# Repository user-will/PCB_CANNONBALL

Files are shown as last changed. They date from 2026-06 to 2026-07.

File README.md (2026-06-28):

# REIL INDUSTRIAL - CANNONBALL

A feature-packed ESP32-C3 development board built around the **ESP32-C3-WROOM-02-N4**, designed to be the last board you need for any project — smart home device, RC car, wearable, or anything else you can dream up.

The big pitch: pull a single-cell LiPo or Li-ion from an old vape, plug it into the JST PH connector, and go. The board handles charging, protection, and fuel gauging — no external circuitry needed.

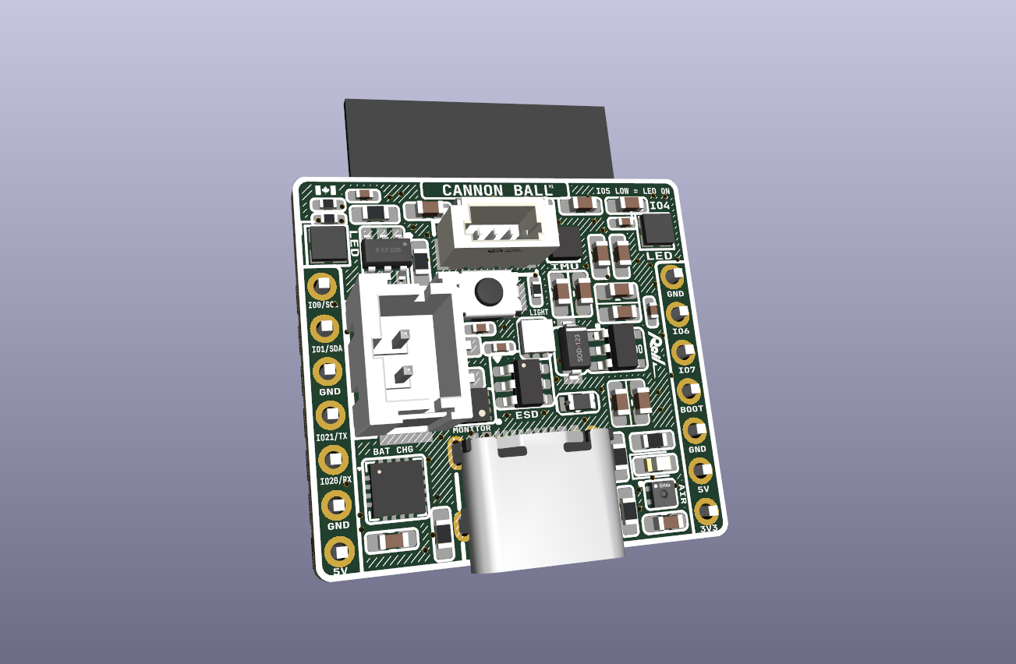
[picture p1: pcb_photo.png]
PCB Photo


---

## Features

- **MCU** — ESP32-C3-WROOM-02-N4 (RISC-V, 2.4 GHz Wi-Fi + BLE, 4 MB flash)
- **USB protection** — USBLC6-4SC6 TVS diode array on the USB lines
- **Battery charging** — BQ24075RGT linear charger (100 mA default, 500 mA selectable via GPIO)
- **Battery protection** — DW01A + FS8205A dual MOSFET pack (over-charge, over-discharge, short circuit)
- **Battery monitoring** — MAX17048 fuel gauge over I2C with low-battery alert
- **3.3 V regulation** — AP2112K-3.3 LDO
- **Addressable LEDs** — SK6812-EC20 RGB LEDs switched via DMG2301L MOSFET
- **IMU** — LSM6DS3 (6-axis accelerometer + gyroscope, I2C)
- **Temp & humidity** — SHT40 (I2C)
- **Light sensor** — VEML6030 ambient light sensor (I2C)
- **I2C expansion** — JST SH 1.0 mm 4-pin connector (3.3 V, GND, SDA, SCL)
- **Battery connector** — JST PH 2.0 mm 2-pin

---

## Power

| Rail | Source | Voltage | Notes |
|---|---|---|---|
| USB-C | External | 5 V nominal, **6 V max** | Limited by AP2112K-3.3 LDO max input. Do not exceed 6 V on the 5 V pins or USB input. |
| 5V pin (J5/J6) | External or VBUS | 5 V nominal, **6 V max** | Same rail as USB VBUS — feeds the LDO and charger directly. |
| 3V3 pin (J4/J6) | AP2112K-3.3 LDO | **3.3 V exactly** | If powering the board externally via the 3V3 pin (bypassing the LDO), supply a regulated 3.3 V. The ESP32 and all peripherals run at 3.3 V with a ±0.3 V tolerance — do not exceed 3.6 V or drop below 3.0 V. |

---

## Pin Reference

| GPIO | Function | Notes |
|---|---|---|
| 3 | MAX17048 alert | Active-low interrupt when battery is low |
| 4 | SK6812 data | Addressable LED data line |
| 5 | LED enable (MOSFET) | Pull **high** to enable LEDs, low to disable |
| 10 | BQ24075 EN1 (charge rate) | Pull **high** to increase charge current from 100 mA to 500 mA |

---

## Bill of Materials

| Reference | Part | Function |
|---|---|---|
| U1 | ESP32-C3-WROOM-02-N4 | Main MCU |
| U2 | BQ24075RGT | Li-ion/LiPo battery charger |
| U3 | MAX17048 | Battery fuel gauge (I2C) |
| U4 | DW01A | Battery protection IC |
| U5 | FS8205A | Dual MOSFET for battery protection |
| U6 | AP2112K-3.3 | 3.3 V LDO regulator |
| U7 | USBLC6-4SC6 | USB ESD/TVS protection |
| U8 | LSM6DS3 | 6-axis IMU (I2C) |
| U9 | SHT40 | Temperature & humidity sensor (I2C) |
| U10 | VEML6030 | Ambient light sensor (I2C) |
| Q3 | 2N7002K | N-channel MOSFET (LED power switch) |
| LED1+ | SK6812-EC20 | Addressable RGB LEDs |

---

## Opening in KiCad

1. Clone or download this repo
2. Open KiCad and select **File → Open Project**
3. Navigate to the repo folder and open `CANNONBALL.kicad_pro`

All schematic symbols and footprints are either embedded in the project files or included in the `jlcpcb.pretty/` and `jlcpcb.kicad_sym` local libraries — no additional library setup required.

---

## Battery Compatibility

Any single-cell LiPo or Li-ion (3.6–4.2 V nominal) will work. The onboard protection circuit guards against:
- Over-charge (> 4.2 V)
- Over-discharge (< 2.5 V)
- Short circuit / over-current

Cells salvaged from vapes, old phones, or RC packs all work fine. Use the JST PH 2.0 mm 2-pin connector (positive on pin 1).

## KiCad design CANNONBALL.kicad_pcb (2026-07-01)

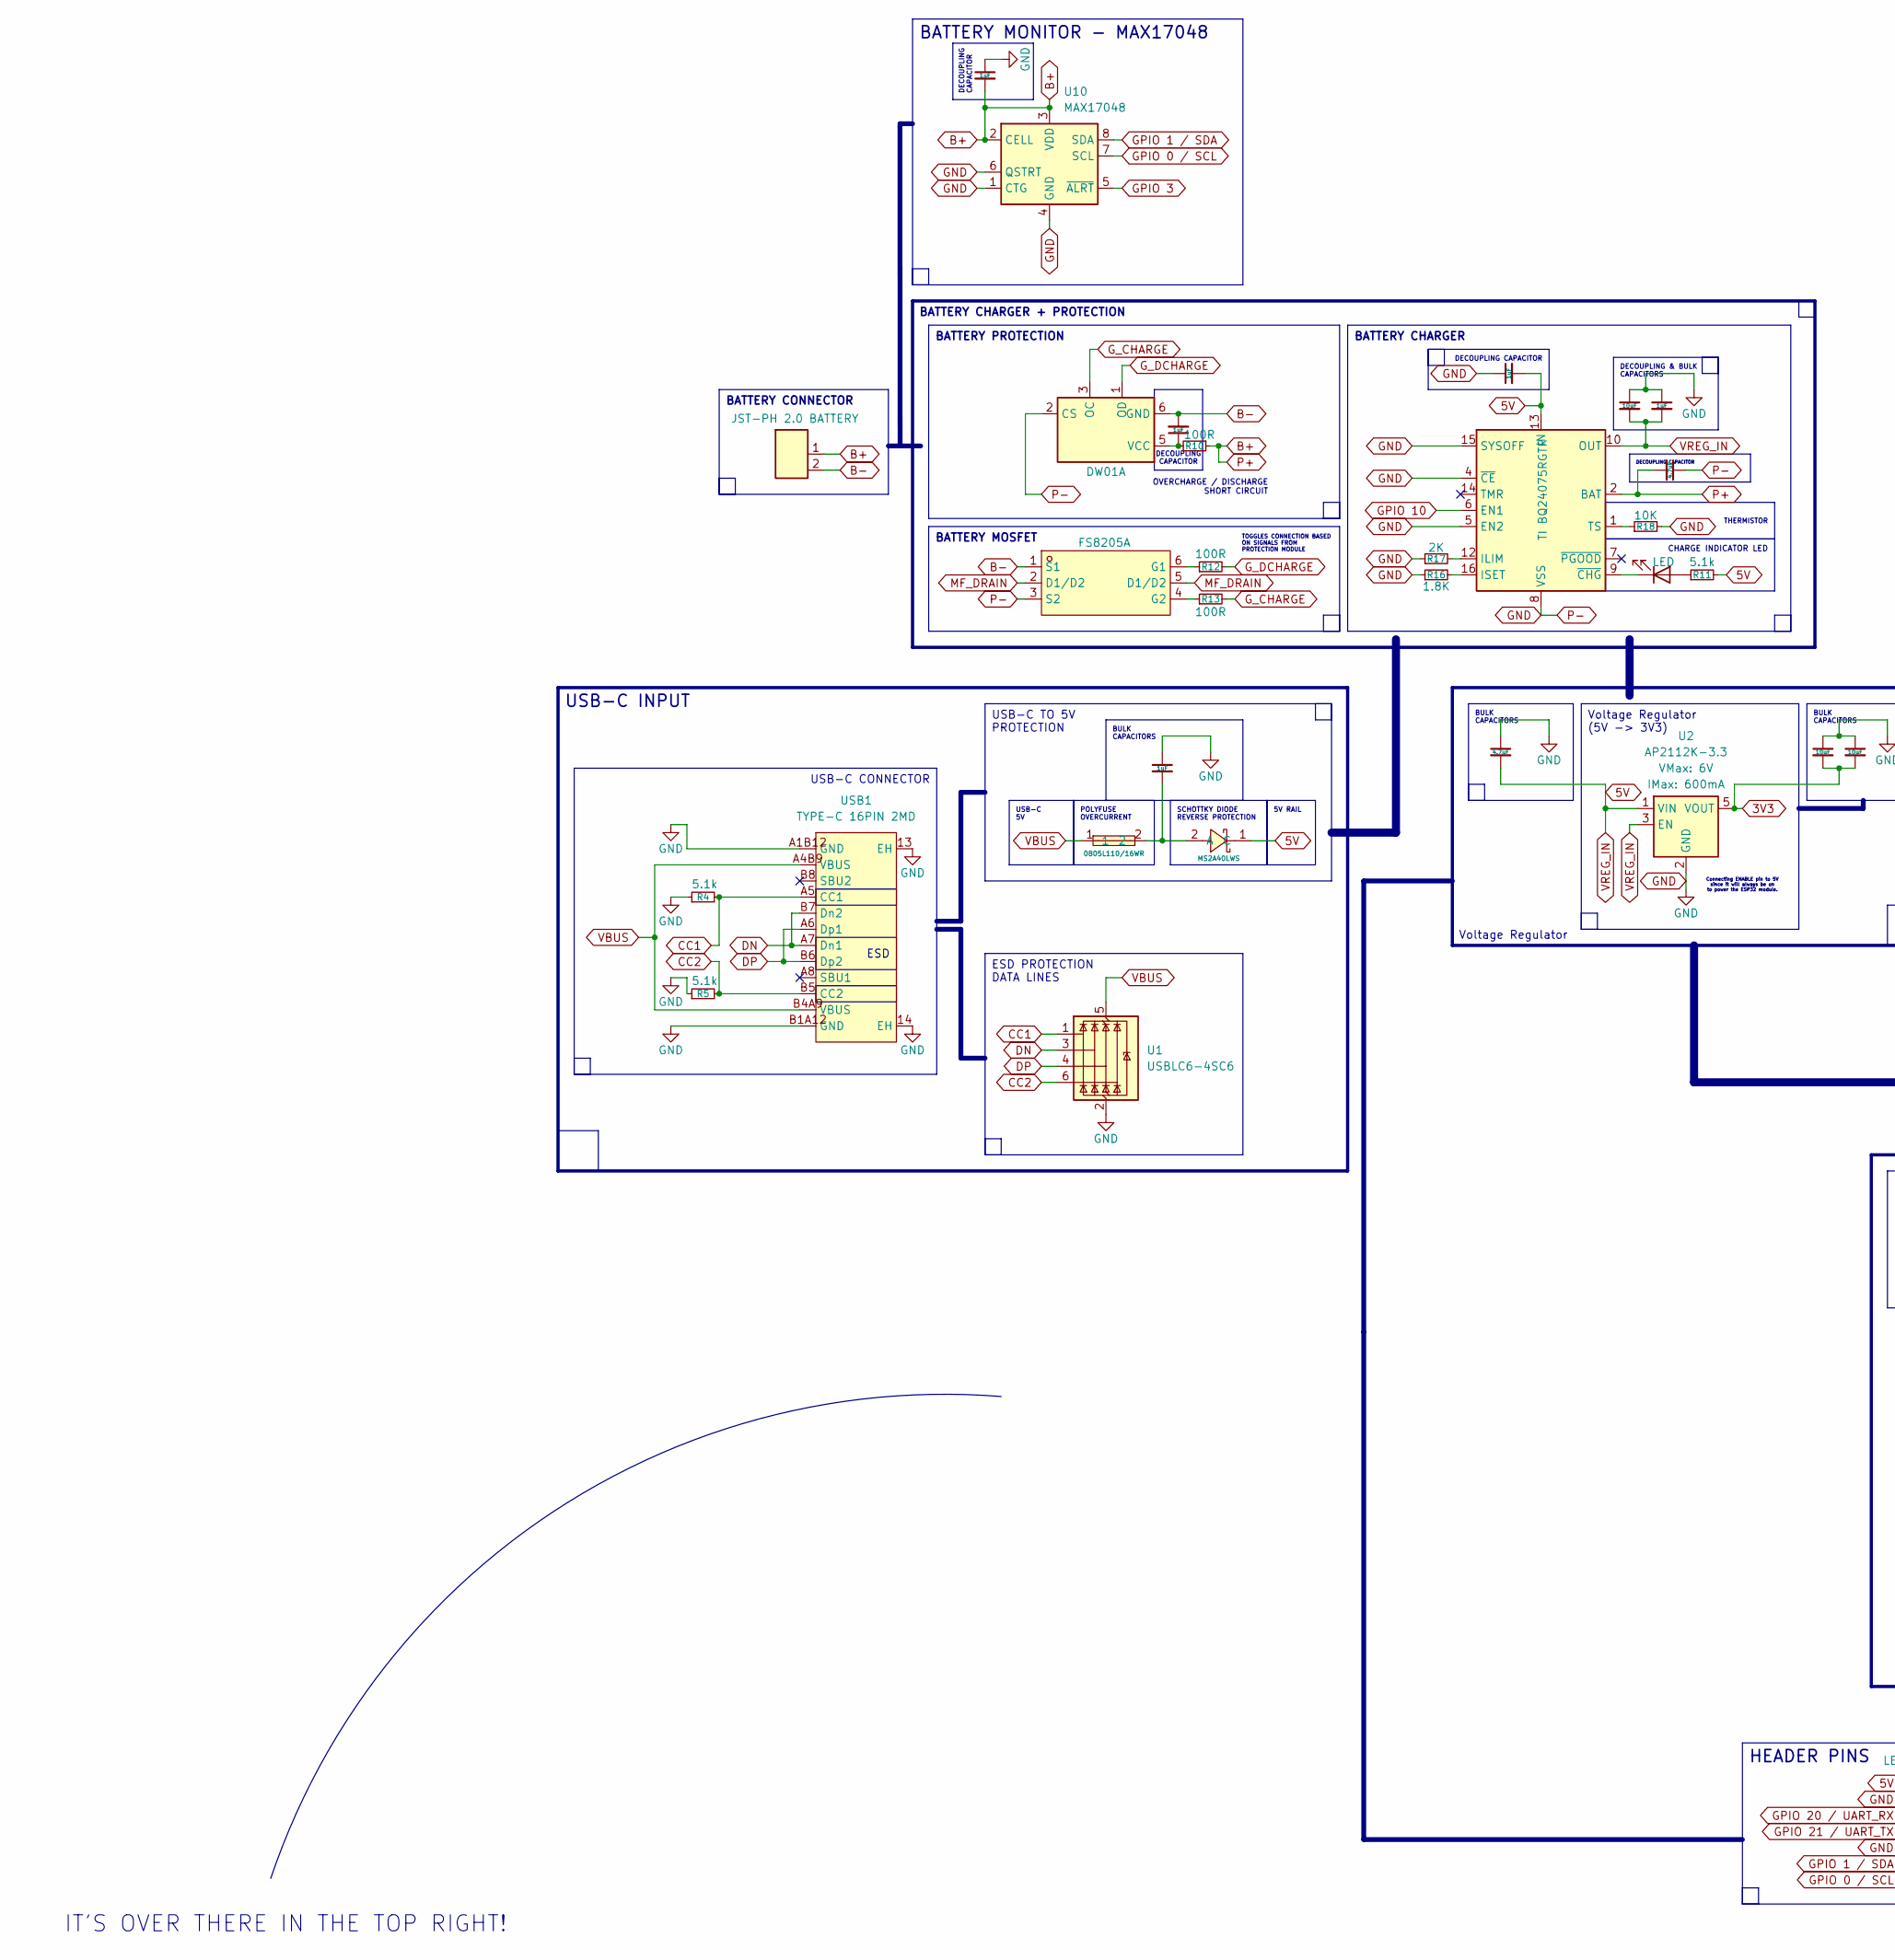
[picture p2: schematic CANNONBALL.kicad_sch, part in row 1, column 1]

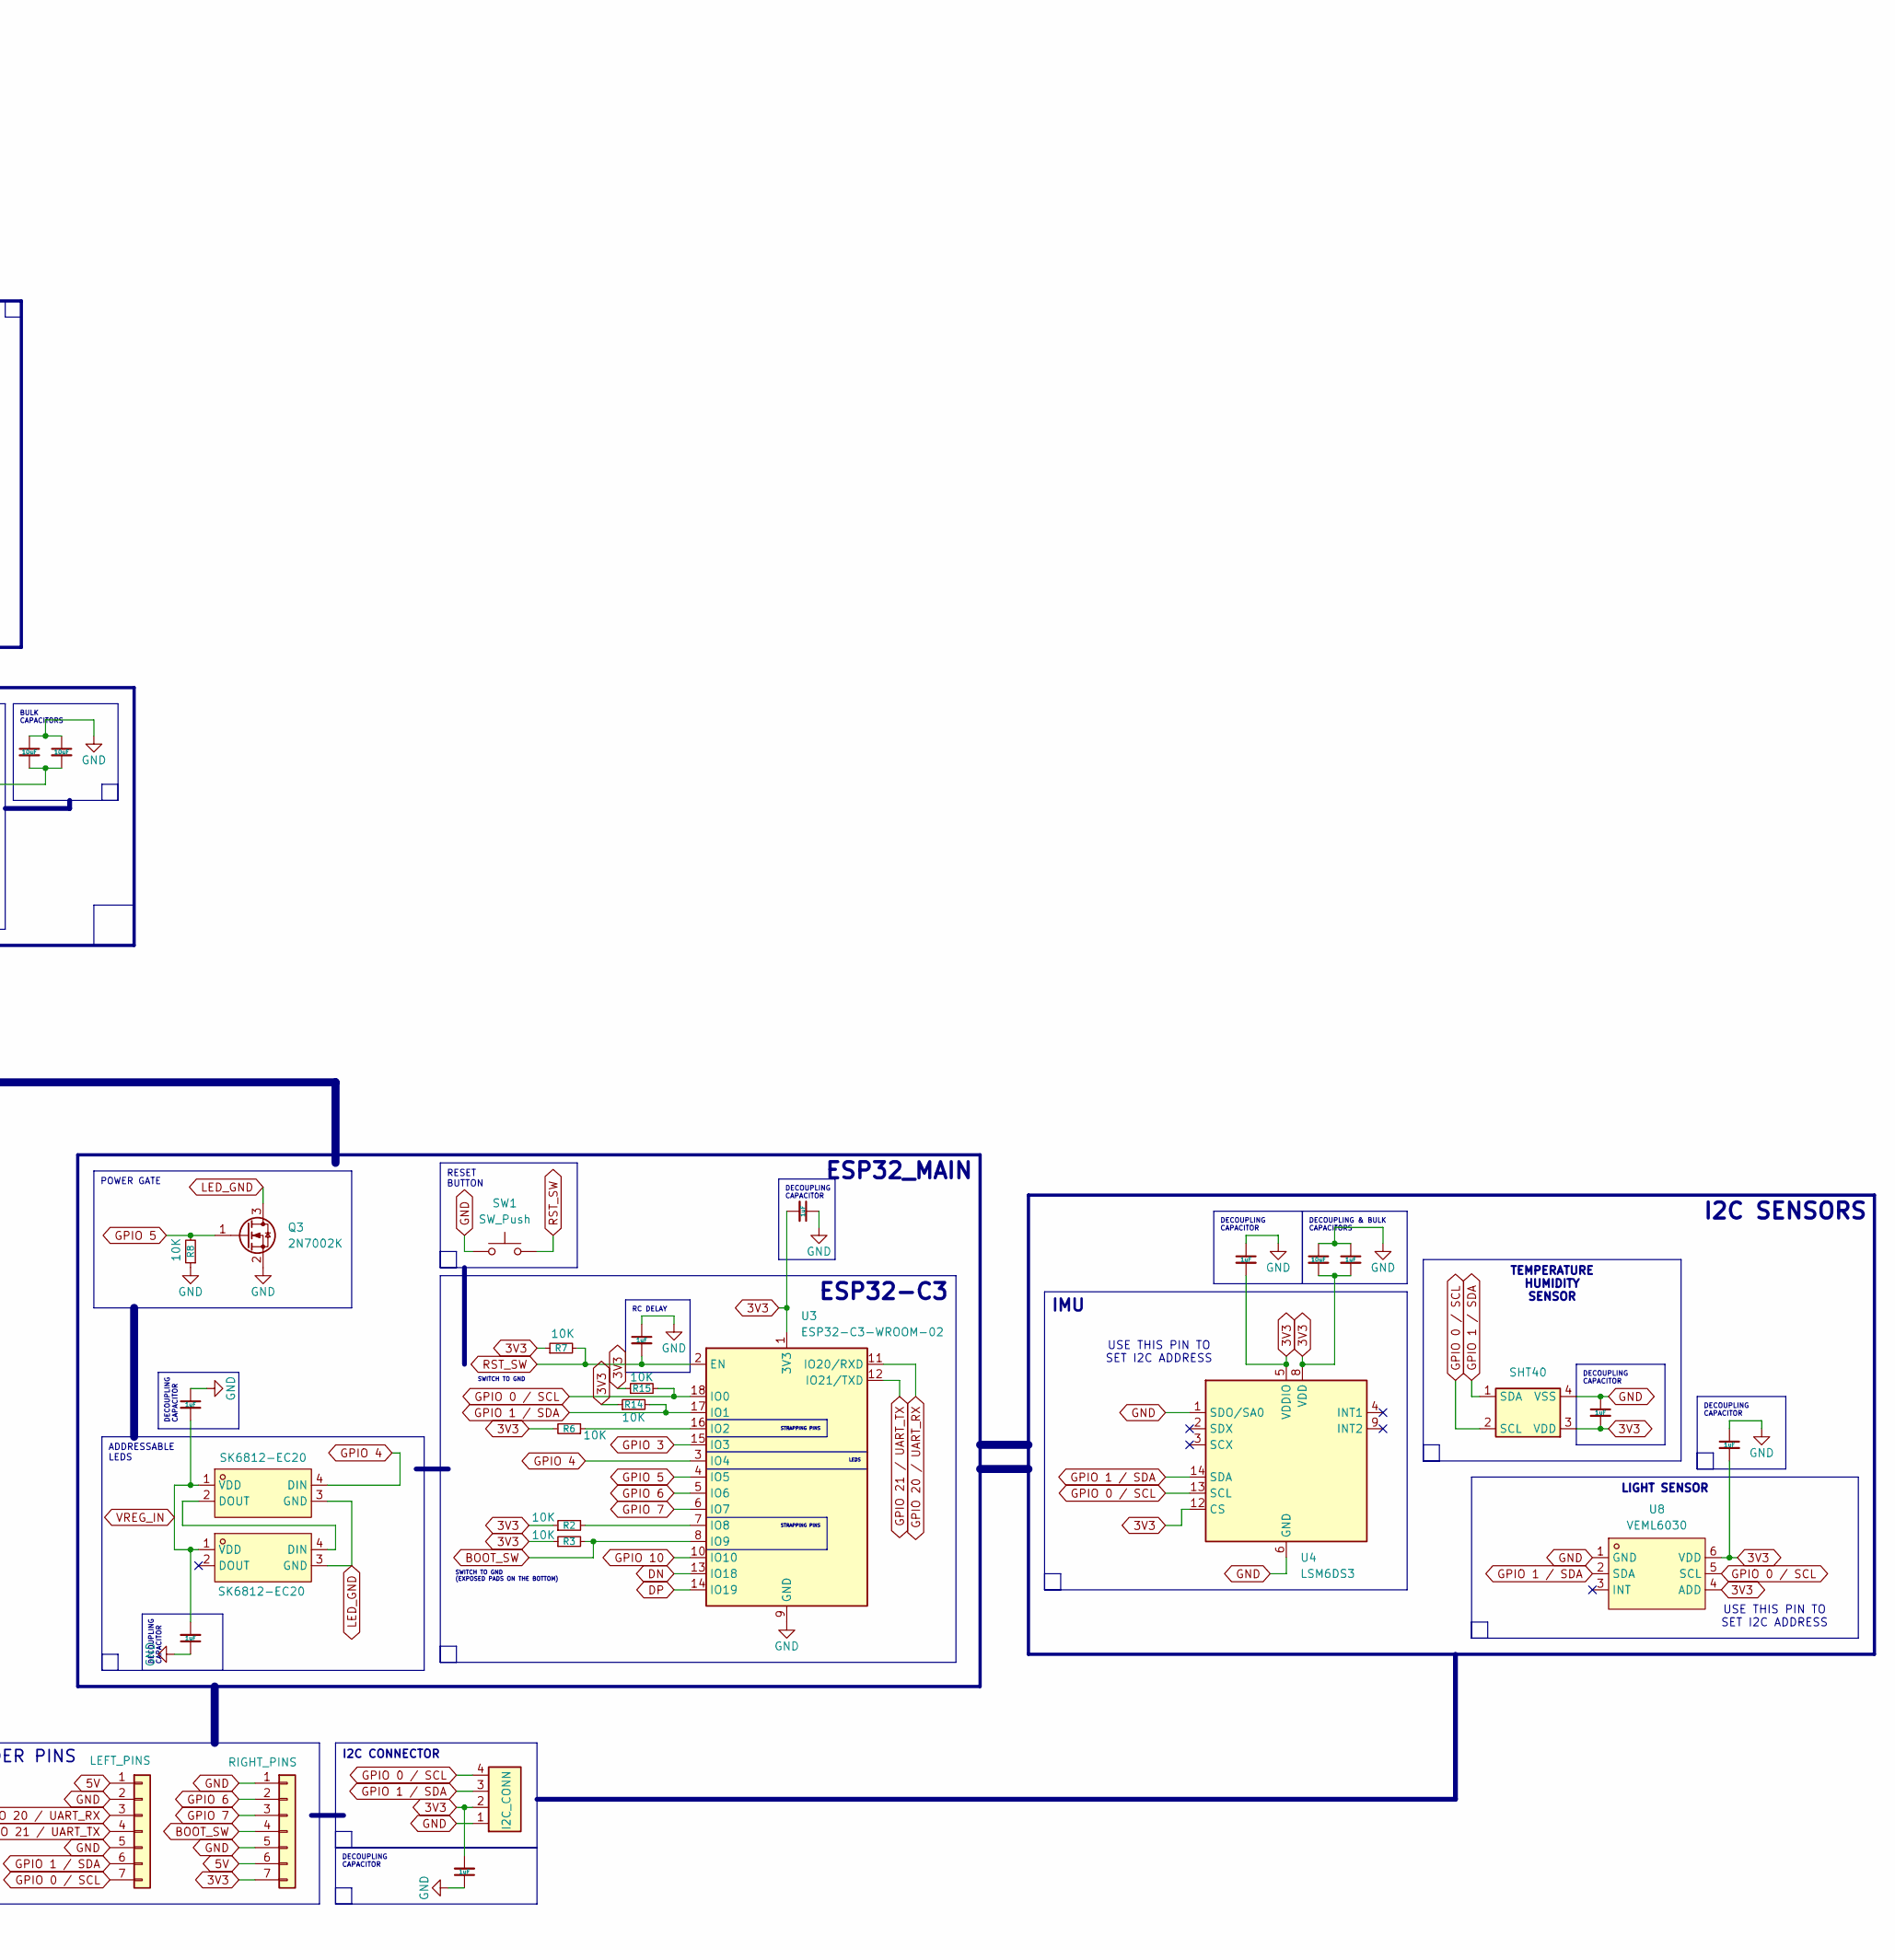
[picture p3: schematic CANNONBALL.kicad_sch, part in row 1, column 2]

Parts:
C1, C3, C10, C11, C12, C14, C16, C18, C20, C21: 1uF; C_0603_1608Metric_Pad1.08x0.95mm_HandSolder
C6, C15: 4.7uF; C_0603_1608Metric_Pad1.08x0.95mm_HandSolder
C8, C9, C17: 10uF; C_0603_1608Metric_Pad1.08x0.95mm_HandSolder
C13: 10uF; C_0402_1005Metric_Pad0.74x0.62mm_HandSolder
C19, C22, C23, C24: 1uF; C_0402_1005Metric_Pad0.74x0.62mm_HandSolder
D2: MS2A40LWS; SOD-323_L1.7-W1.25-LS2.5-RD; MPN MS2A40LWS; LCSC Part C7380001
D4: LED; LED_0603_1608Metric_Pad1.05x0.95mm_HandSolder
F2: 0805L110/16WR; F0805; MPN 0805L110/16WR; LCSC Part C47345575
J3: JST-PH 2.0 BATTERY; CONN-TH_2P-P2.00_XUNPU_WAFER-PH2.0-2PLB
J4: I2C_CONN; CONN-SMD_4P-P1.00_ZX-SH1.0-4PLN
J5: LEFT_PINS; PinHeader_01x07_P2.54mm_Vertical_THT_D1mm
J6: RIGHT_PINS; PinHeader_01x07_P2.54mm_Vertical_THT_D1mm
LED1, LED2: SK6812-EC20; LED-SMD_4P-L2.0-W2.0-BR; MPN SK6812-EC20; LCSC Part C2909058
Q1: FS8205A; SOT-23-6_L2.9-W1.6-P0.95-LS2.8-BR; MPN FS8205A; LCSC Part C2830320
Q3: 2N7002K; SOT-23
R2, R3, R7, R8, R14, R15: 10K; R_0402_1005Metric_Pad0.72x0.64mm_HandSolder
R4, R5, R11: 5.1k; R_0603_1608Metric_Pad0.98x0.95mm_HandSolder
R6, R18: 10K; R_0603_1608Metric_Pad0.98x0.95mm_HandSolder
R10, R12, R13: 100R; R_0603_1608Metric_Pad0.98x0.95mm_HandSolder
R16: 1.8K; R_0603_1608Metric_Pad0.98x0.95mm_HandSolder
R17: 2K; R_0603_1608Metric_Pad0.98x0.95mm_HandSolder
SW1: SW_Push; KEY-SMD_L4.0-W3.0-LS4.9-1
U1: USBLC6-4SC6; SOT-23-6
U2: AP2112K-3.3; SOT23-5
U3: ESP32-C3-WROOM-02
U4: LSM6DS3; LGA-14_2x2mm_P0.35mm_LayoutBorder3x4y
U5: DW01A; SOT-23-6
U6: TI BQ24075RGTR; VQFN-16-1EP_3x3mm_P0.5mm_EP1.6x1.6mm
U7: SHT40; Sensirion_DFN-4_1.5x1.5mm_P0.8mm_SHT4x_NoCentralPad
U8: VEML6030; SENSORS-SMD_VEML6030; MPN VEML6030; LCSC Part C132182
U10: MAX17048; DFN-8_2x2mm_P0.5mm_EP1.2x0.8mm
USB1: TYPE-C 16PIN 2MD; USB-C-SMD_TYPE-C-16PIN-2MD-073; MPN TYPE-C 16PIN 2MD(073); LCSC Part C2765186

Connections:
3V3: C8.2, C9.2, C10.2, C16.2, C17.2, C18.2, C20.2, C21.2, C22.2, J4.2, J6.7, R2.1, R3.1, R6.2, R7.1, R14.1, R15.1, U2.5 (VOUT), U3.1 (3V3), U4.5 (VDDIO), U4.8 (VDD), U4.12 (CS), U7.3 (VDD), U8.4 (ADD), U8.6 (VDD)
5V: C6.2, C12.2, C13.2, C14.2, C19.2, C23.2, D2.1 (C), J5.1, J6.6, LED1.1 (VDD), LED2.1 (VDD), R11.2, U2.1 (VIN), U2.3 (EN), U6.10 (OUT), U6.11 (OUT), U6.13 (IN)
B+: C15.2, C24.2, J3.1, R10.1, U6.2 (BAT), U6.3 (BAT), U10.2 (CELL), U10.3 (VDD)
B-: C11.2, J3.2, Q1.1 (S1), U5.6 (GND)
BOOT_SW: J6.4, R3.2, U3.8 (IO9)
CC1: R4.2, U1.1 (I/O1), USB1.A5 (CC1)
CC2: R5.2, U1.6 (I/O4), USB1.B5 (CC2)
DN: U1.3 (I/O2), U3.13 (IO18), USB1.A7 (Dn1), USB1.B7 (Dn2)
DP: U1.4 (I/O3), U3.14 (IO19), USB1.A6 (Dp1), USB1.B6 (Dp2)
GND: C1.1, C3.1, C6.1, C8.1, C9.1, C10.1, C12.1, C13.1, C14.1, C15.1, C16.1, C17.1, C18.1, C19.1, C20.1, C21.1, C22.1, C23.1, C24.1, J4.1, J5.2, J5.5, J6.1, J6.5, Q1.3 (S2), Q3.2 (S), R4.1, R5.1, R8.1, R16.1, R17.1, R18.2, SW1.1, U1.2 (GND), U2.2 (GND), U3.9 (GND), U3.19 (GND), U4.1 (SDO/SA0), U4.6 (GND), U4.7 (GND), U5.2 (CS), U6.4 (~CE), U6.5 (EN2), U6.8 (VSS), U6.15 (SYSOFF), U6.17 (VSS), U7.4 (VSS), U8.1 (GND), U10.1 (CTG), U10.4 (GND), U10.6 (QSTRT), U10.9 (GND), USB1.13 (EH), USB1.14 (EH), USB1.A1B12 (GND), USB1.B1A12 (GND)
GPIO 0 / SCL: J4.4, J5.7, R15.2, U3.18 (IO0), U4.13 (SCL), U7.2 (SCL), U8.5 (SCL), U10.7 (SCL)
GPIO 1 / SDA: J4.3, J5.6, R14.2, U3.17 (IO1), U4.14 (SDA), U7.1 (SDA), U8.2 (SDA), U10.8 (SDA)
GPIO 3: U3.15 (IO3), U10.5 (~ALRT)
GPIO 4: LED1.4 (DIN), U3.3 (IO4)
GPIO 5: Q3.1 (G), R8.2, U3.4 (IO5)
GPIO 6: J6.2, U3.5 (IO6)
GPIO 7: J6.3, U3.6 (IO7)
GPIO 10: U3.10 (IO10), U6.6 (EN1)
GPIO 20 / UART_RX: J5.3, U3.11 (IO20/RXD)
GPIO 21 / UART_TX: J5.4, U3.12 (IO21/TXD)
G_CHARGE: R13.2, U5.3 (OC)
G_DCHARGE: R12.2, U5.1 (OD)
LED_GND: LED1.3 (GND), LED2.3 (GND), Q3.3 (D)
MF_DRAIN: Q1.2 (D1/D2), Q1.5 (D1/D2)
unnamed: C1.2, D2.2 (A), F2.2
unnamed: D4.2 (A), R11.1
unnamed: D4.1 (K), U6.9 (~CHG)
unnamed: LED1.2 (DOUT), LED2.4 (DIN)
unnamed: Q1.6 (G1), R12.1
unnamed: Q1.4 (G2), R13.1
unnamed: R6.1, U3.16 (IO2)
unnamed: R2.2, U3.7 (IO8)
unnamed: C11.1, R10.2, U5.5 (VCC)
unnamed: R17.2, U6.12 (ILIM)
unnamed: R16.2, U6.16 (ISET)
unnamed: R18.1, U6.1 (TS)
RST_SW: C3.2, R7.2, SW1.2, U3.2 (EN)
VBUS: F2.1, U1.5 (VBUS), USB1.A4B9 (VBUS), USB1.B4A9 (VBUS)

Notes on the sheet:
USE THIS PIN TO SET I2C ADDRESS
SWITCH TO GND
OVERCHARGE / DISCHARGE SHORT CIRCUIT
TOGGLES CONNECTION BASED ON SIGNALS FROM PROTECTION MODULE
IT'S OVER THERE IN THE TOP RIGHT!
SWITCH TO GND (EXPOSED PADS ON THE BOTTOM)
Connecting ENABLE pin to 5V since it will always be on to power the ESP32 module.
BULK CAPACITORS
HEADER PINS
I2C SENSORS
DECOUPLING CAPACITOR
BATTERY PROTECTION
Voltage Regulator
LEDS
IMU
ESP32_MAIN
USB-C TO 5V PROTECTION
ESP32-C3
SCHOTTKY DIODE REVERSE PROTECTION
BATTERY CHARGER + PROTECTION
5V RAIL
USB-C CONNECTOR
I2C CONNECTOR
USB-C 5V
CHARGE INDICATOR LED
DECOUPLING CAPACITOR
STRAPPING PINS
BATTERY CONNECTOR
POWER GATE
LIGHT SENSOR
ESD
RESET BUTTON
BATTERY CHARGER
ESD PROTECTION DATA LINES
POLYFUSE OVERCURRENT
BATTERY MOSFET
ADDRESSABLE LEDS
USB-C INPUT
TEMPERATURE HUMIDITY SENSOR
THERMISTOR

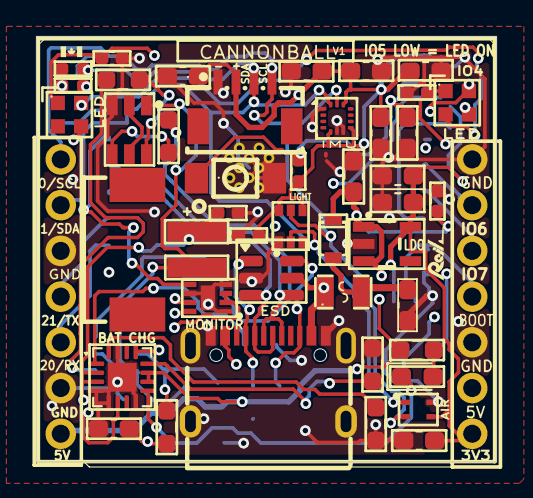
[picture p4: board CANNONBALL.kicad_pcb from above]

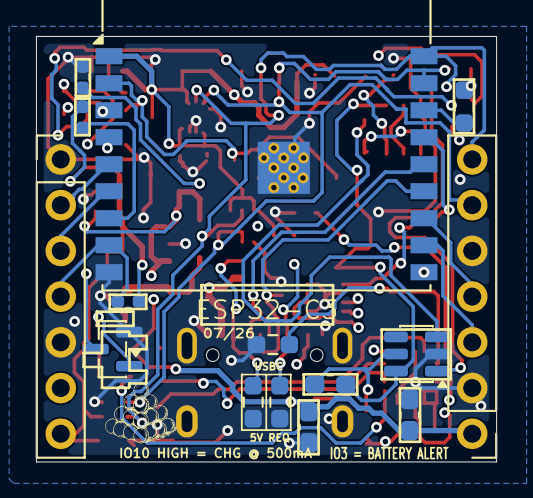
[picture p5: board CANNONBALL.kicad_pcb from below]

Board: 4 copper layers, 25.6 x 23.6 mm, 58 parts (15 on the bottom side), 38 nets.

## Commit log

2026-06-25 Initial commit: ESP32C3 MEGA KiCad project
    Full KiCad project with schematic, PCB layout, custom footprints/symbols,
    and README. Includes battery management, USB protection, IMU, environmental
    sensors, and addressable LED support.
    [ESP32C3_MEGA.kicad_pcb, ESP32C3_MEGA.kicad_sch]
2026-06-25 Fix GPIO10 charge rate pin in README
    Corrects the pin reference table to specify GPIO10 as the BQ24075 EN1
    control pin for switching between 100 mA and 500 mA charge current.
2026-06-25 Add power rail voltage limits to README
    Documents the 6V maximum on the 5V/USB input pins (AP2112K-3.3 LDO
    limit) and the requirement for a regulated 3.3V on the 3V3 pin when
    powering externally.
2026-06-25 Rename project to REIL INDUSTRIAL - CANNONBALL
    Renames all ESP32C3_MEGA files to CANNONBALL, updates all internal
    project name references, clears broken local 3D model path from
    footprint, and updates README title and project file reference.
    [CANNONBALL.kicad_pcb, CANNONBALL.kicad_sch]
2026-06-25 Update silkscreen
    [CANNONBALL.kicad_pcb]
2026-06-25 Fix silkscreen text sizes for JLC manufacturability
    Updated all silkscreen text to 0.5x0.5mm with 0.1mm stroke, matching
    previously verified board spec that passes JLC's process requirements.
    [CANNONBALL.kicad_pcb]
2026-06-28 Add production_files to gitignore and update design files
    [CANNONBALL.kicad_pcb, CANNONBALL.kicad_sch]
2026-06-28 Fix N-channel MOSFET logic and BOM in README
2026-07-01 Update KiCad project settings and add round tracks config
    - Update default pad dimensions in project settings
    - Add BOM field columns (MPN, LCSC Part, Manufacturer, etc.)
    - Add round tracks plugin config file
    [CANNONBALL.kicad_pcb]
